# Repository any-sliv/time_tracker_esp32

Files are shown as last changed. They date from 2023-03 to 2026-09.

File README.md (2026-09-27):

# Cube Time Tracker ESP32

**:exclamation: --This project is still under heavy development. First release is coming!--**
**Desktop app - cube's receiving end is in development.**
</br>

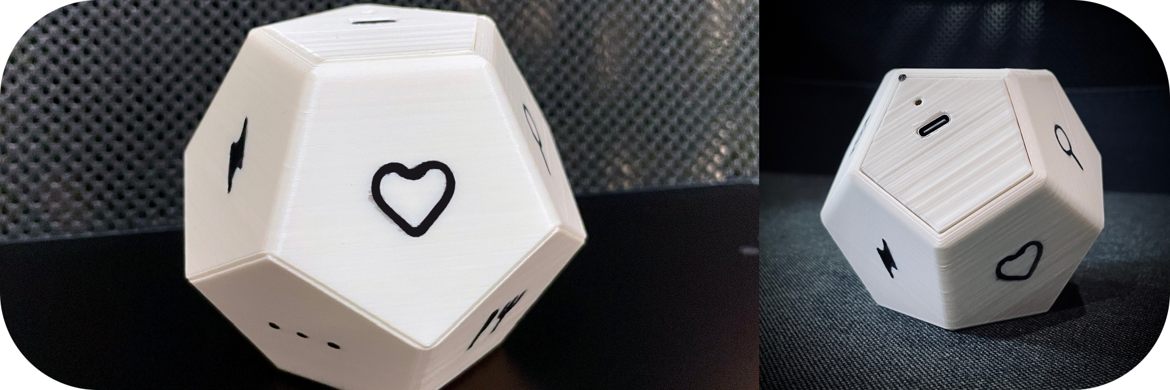
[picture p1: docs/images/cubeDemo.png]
:game_die: tracker
 

</br>

Open source time tracker in a form of cube :game_die: Each wall has a symbol which describes activity you might be doing. Flip the wall and the clock is ticking! Cube pairs with a **desktop app** (under development), which shows you the insights into time you spent on particular activities. 
</br>

In order to start with your own DIY tracker you will go through these steps:
- :hammer: Obtain and build (esp32 board, accelometer board, battery and enclosure)
- :arrow_double_up: Upload firmware to ESP32 board
- :mag: Connect to tracker with desktop app
- :rocket: Go thru initial configuration process

# Hardware Build

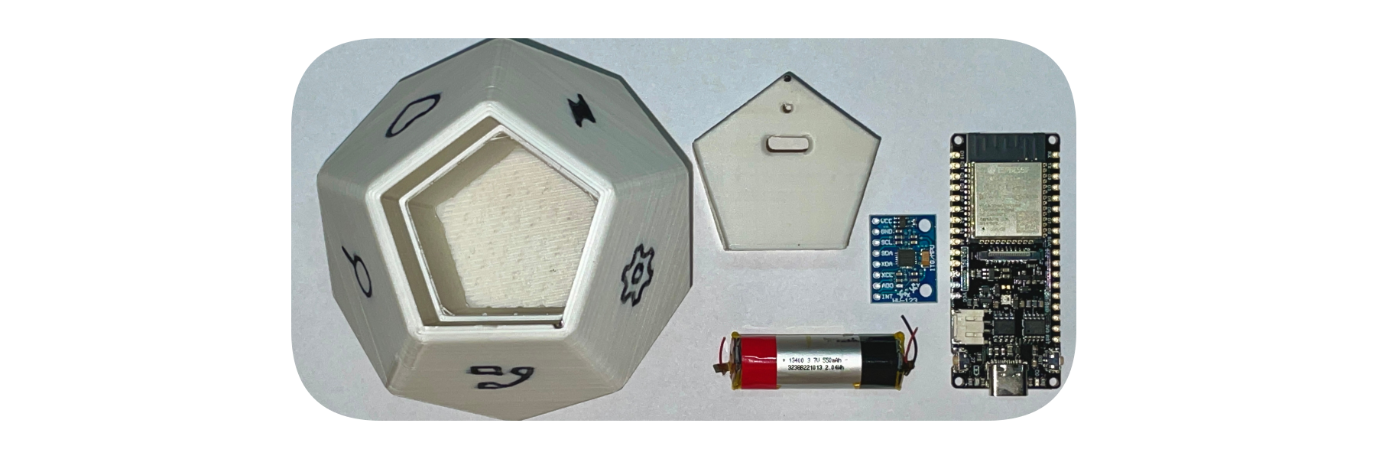
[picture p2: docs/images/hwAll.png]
All the elements


## Components

Alright, time to build the tracker :game_die: Here is the list of parts you need :gear:

- [DFRobot Firebeetle ESP32](https://wiki.dfrobot.com/FireBeetle_Board_ESP32_E_SKU_DFR0654) (currently the only supported board)
- [MPU6050 Accelometer](https://components101.com/sensors/mpu6050-module)
- Battery (lithium) of your choice, single cell, with the right shape you can fit any up to 1000mAh. Mind that Firebeetle has no any protection circuit
- 3D printed parts (models available in docs/ )
  - Enclosure 
  - Insert which will hold your electronics
- Two tiny screws

Equipment you might need for assembly:
- Soldering iron
- Tape (duct or double sided)
- Screwdriver

## Assembly

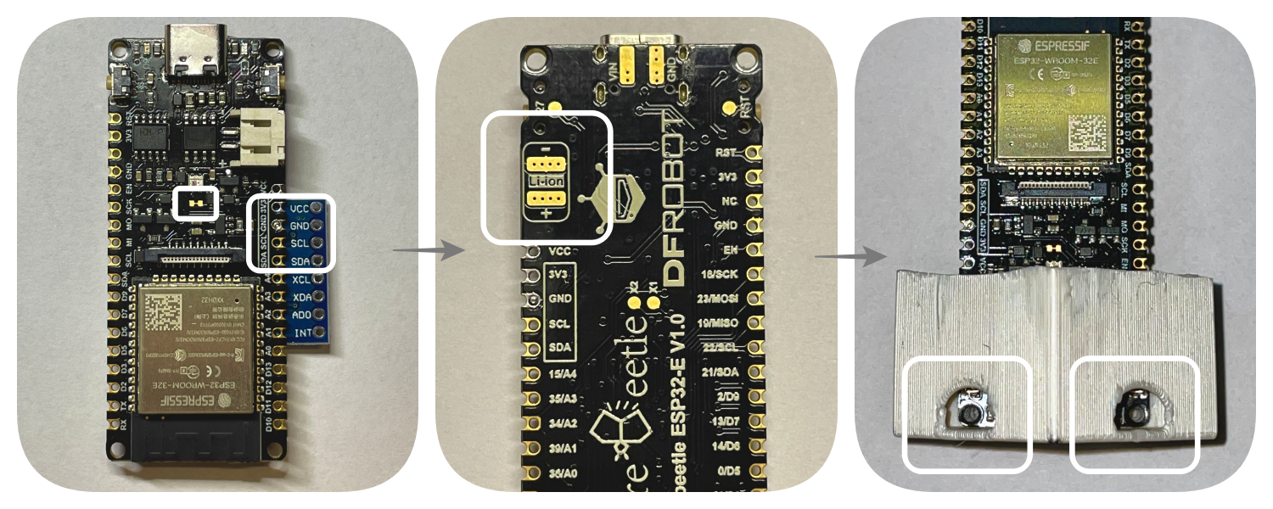
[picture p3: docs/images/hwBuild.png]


- Cut the trace between exposed pads (be careful not to cut the other traces)
- Solder MPU6050 to Firebeetle. Match the pins from MPU :exclamation: Mind that MPU's VCC pin should connect to 3V3 on the beetle
- Take your battery and solder its terminals to pads on the beetle's bottom side
- Attach battery to Firebeetle board (suggestion: tape)
- Put your assembled electronics into the printed insert and thighten screws through the holes in insert

:checkered_flag: I hope you didn't screw it up (lol you get it, the last step with screws).
</br>
Connect USB-C cable, charge the battery and upload software!

## Hardware additional info

### Power consumption

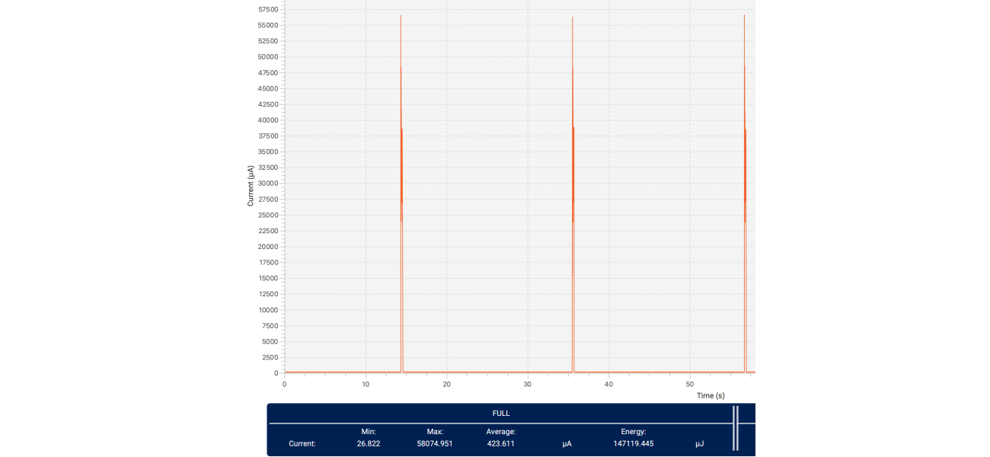
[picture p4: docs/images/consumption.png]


An average current consumption on FireBeetle is around 500uA. Time on battery you can calculate as follows: </br>`90% * capacity[mAh] / avg_consumption[mA] = time[h]`. </br> Other boards might yield different results. When looking for an alternative board pay attention to what components on the board are powered from 3V3 rail, an example is USB to UART converter present on almost every board, they are usually connected to 3V3, so they will drain your battery. Lolin32 Lite seems to be the closest suitable alternative, but since it has no connection from battery to ESP32 you might to hack a resistor divier and connect it to some analog input.
</br>
Cube app will remind you about low battery level.

# Software Build

Time to upload software into the tracker. Or you might want to tweak the software a lil bit on your own?

### Build 
Project is build with [PlatformIO](https://platformio.org) framework.

- Install PlatformIO extension in VSCode
- PIO Home > Platforms > Embedded > Download and install "Espressif 32" **version 6.1.0** (includes ESP-IDF v5.0.1)
- Make sure you cloned/pulled this git repository
- Download submodules `git submodule update --init` </br> NimBLE repo in {project}/app/ble/esp32-nimble-cpp should be downloaded. If not, use `git submodule add https://github.com/h2zero/esp-nimble-cpp` and then update submodule
- Build project and upload binaries using PlatformIO buttons/shortcuts at the bottom status bar

Off you go! In case of errors - clean and build.

## Troubleshooting
- Firebeetle board not recognized (OS X): http://www.wch-ic.com/downloads/CH341SER_MAC_ZIP.html

Otherwise... Plug the cube and run PlatformIO serial monitor, lookup the errors in the console

## Found a bug?
If you found a :bug: please report it via issues tab

## Known issues
Time drifts +/- 5%. 8.5 MHz internal RTC clock issue - to be fixed in upcoming ESP-IDF updates, you can implement it already using [esp-idf issue commit](https://github.com/espressif/esp-idf/commit/a0ed82525ec03bfe3a3edc46fbbb2c8449db3e14)

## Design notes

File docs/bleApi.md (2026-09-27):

# Time tracker ESP32 BLE API

This documentation provides information on the Bluetooth Low Energy (BLE) communication protocol API used in a time tracker. The documentation is organized into sections that correspond to the different services supported by the application. Each service includes one or more characteristics that describe the data being transmitted over BLE. The documentation also includes guidelines for developers and users.
</br>

### Tracker goes zzz...
The device is sleeping most of the time, what also means its BLE controller is turned off. Waking up happens once per five minutes or position has changed, and it advertises for a few seconds — so be quick and listen for it... basically always.
</br>
Once you are **connected**, the tracker holds itself awake for up to **30 seconds** rather than hanging up mid-transfer. It ends the session early when either the position backlog has been drained (see Position below) or you write the Sleep characteristic. Note that after it sleeps it may not advertise again for up to five minutes, so finish everything you need in one session.
</br>
Mind that tracker is a low power device and its juice comes from battery, so try use/read/write as least and quick as possible.
</br>

## Services and characteristics:
- **Service**
  - **Characteristic**
  - ...

### **Time tracker advertise** UUID: 8227dcb2-30e3-11ed-a261-0242ac120002
</br>

- **Device manufacturer name** (UUID:--)
  - **Device manufacturer name** (UUID:2A29)
    </br>
    .
    
- **Firmware revision** (UUID:--)
  - **Firmware revision** (UUID:2A26)
    </br>
     .
- **Battery** (UUID: --)
  - **Battery**
    </br>
    This is BT SIG adopted service. Data is a battery level [%]. Details: https://www.bluetooth.com/specifications/specs/battery-service/
    </br>
    Device updates value onRead action. Read twice to get actual value.

- **Current Time** (UUID: --)
  - **Current Time** (UUID: 2A2B)
    </br>
    | Data | Length (bytes) | Description | Properties |
    | -------- | -------- | -------- | -------- | 
    | int64_t | 8 | Epoch (unix) time | READ + WRITE |

    Device has no RTC battery, thus it might lose time. Using this characteristic device can have its system time updated.
    Device updates value onRead action. Read twice to get actual value.

- **Sleep** (UUID: --)
  - **Sleep** (UUID: 646b8837-cea9-4006-be25-00c990029e90)
    | Data | Length (bytes) | Description | Properties |
    | -------- | -------- | -------- | -------- | 
    | uint8_t | 1 | Sleep request | WRITE |

    Device stays in sleep mode most of the time. Use this characteristic to force device to enter sleep mode. Recommended to use after done with processing all data from the tracker. Write (uint8_t)<1> to force sleep.

- **IMU** (UUID: 7bef916a-3141-11ed-a261-0242ac120000)
  - **Position** (UUID: 7bef916a-3141-11ed-a261-0242ac120001)
    | Data | Length (bytes) | Description | Properties |
    | -------- | -------- | -------- | -------- | 
    | \<startTime>,\<face>[;\<startTime>,\<face>]... | variable, up to MTU-3 | Batch of tracker positions and their start times | READ |

    ASCII text. One read returns **as many records as fit in the negotiated MTU minus 3 bytes**, separated by `;`. Records are **oldest first**, and ordering holds across successive reads, so a client can simply append each batch.

    Example data (three records in one read):
    ```
    1688587818,8;1688589019,4;1688590151,8
    ```

    - `startTime` is decimal epoch (unix) seconds at which the face was registered.
    - `face` is the cube face. It may read **4294967295** (`-1` as unsigned), which means the tracker saw a position that matches none of its calibrated faces — treat it as "unknown", not as a real face.
    - **A single record is a valid batch of one**, so a client written against the older one-record-per-read format keeps working unchanged.
    - At a very small (unnegotiated, 23-byte) MTU a single record can exceed the budget. The tracker sends it anyway rather than stalling; the value is retrievable via a read-blob continuation.

    Each tracker flip is saved in order to be sent later, so a backlog accumulates while there is no BLE connection.
    </br> Device updates value onRead action. Read twice to get actual value. First read might be zero, always read at least twice.
    BLE Client should read as long as value in characteristic is other than 0, due to fact there might be more data to read than just from one position change.
    </br> Once the tracker has handed over at least one record and a subsequent read returns 0, it treats the backlog as drained and goes to sleep shortly after — so issue any other work (calibration, time set) before finishing the drain, or keep the connection busy.

  - **Calibration** (UUID: 7bef916a-3141-11ed-a261-0242ac120002)
    </br>
    | Data | Length (bytes) | Description | Properties |
    | -------- | -------- | -------- | -------- | 
    | \<status>,\<face> | 4-5 | Client request or server response | WRITE + READ |

    Calibration characteristic is used during initial configuration to calibrate IMU/accelometer. Requests from client initiate calibration and server responds with result and calibrated face number. Client initiates calibration of each position/face/wall with writing (uint8_t)<1> to the characteristic. Table below represents values server might set as a result.

    | Value | Definition |
    | -------- | -------- | 
    | -1 | Error, calibration failed |
    | 0 | Idle, calibration not initiated |
    | 1 | Position already exists/duplicate | 
    | 2 | Position registered OK | 
    | 3 | Calibration done |

    Flow of calibration process:
    - Client requests calibration - write (uint8_t)<1> to characteristic
    - Tracker responds with a write to characteristic with response from table above
    - Client reads from characteristic. If position OK/already exists - flip the cube/tracker
    - Client requests calibration - write (uint8_t)<1> to characteristic
    - ...
    - Until done

uuidDeviceFirmwareUpdateService = "00009921-1212-efde-1523-785feabcd123"; 
uuidDeviceFirmwareDataCharacteristic = "00009921-1212-efde-1523-785feabcd124"; 
uuidDeviceFirmwareControlCharacteristic = "00009921-1212-efde-1523-785feabcd125"; 

- **Device firmware update** (UUID:00009921-1212-efde-1523-785feabcd123)
  - **Device firmware control** (UUID:00009921-1212-efde-1523-785feabcd125)
    </br>
    DFU characteristic, use it for initiating update and checking status.

    | Value | Definition | Description |
    | -------- | -------- | -------- |
    | 0 | OTA Start Request | Send to server to request DFU begin |
    | 1 | OTA Start Request acknowledged | Server sets value |
    | 2 | OTA Start Request not acknowledged | Server sets value |
    | 3 | OTA Done Request | Send to server to request DFU end |
    | 4 | OTA Done Request acknowledged | Server sets value | 
    | 5 | OTA Done Request not acknowledged | Server sets value |

    Process flow:
    </br>
    Client requests DFU and after second reads from characteristic what server has responded. In case of success split firmware file (.bin) into chunks of a `chunkSize = BLE MTU size - 3`. Send all the chunks to data characteristic (no response). After sending all data, write a done request to this characteristic, wait 3-5 seconds and read a value if end has been acknowledged. If so, device will reboot in a couple of seconds.

  - **Device firmware update data** (UUID:00009921-1212-efde-1523-785feabcd124)
    </br>
    Send here chunks of firmware file

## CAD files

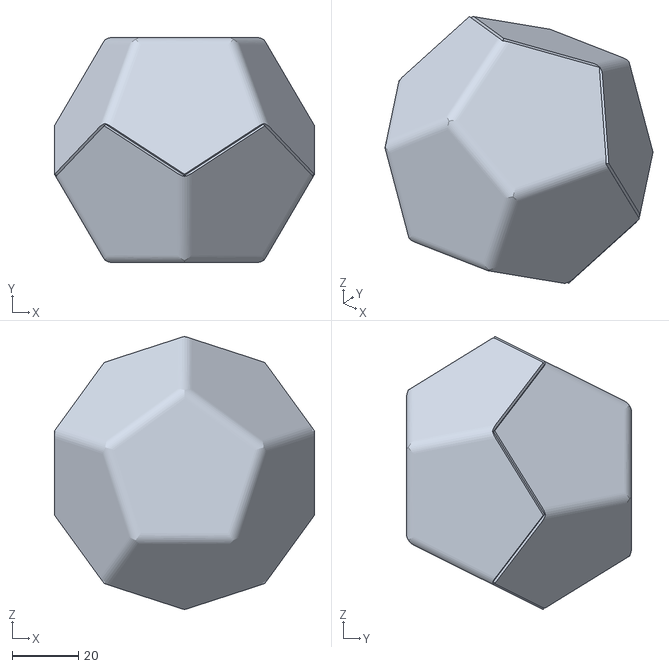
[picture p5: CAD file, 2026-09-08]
docs/3dmodel/cube.stl
78.5 x 68.0 x 82.5

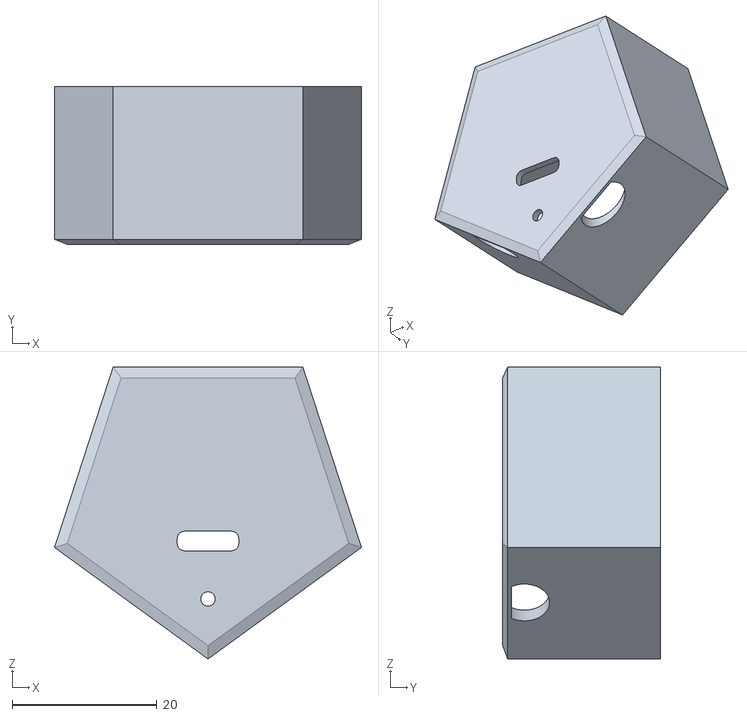
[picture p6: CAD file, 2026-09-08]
docs/3dmodel/cubeInsert.stl
42.4 x 21.8 x 40.3

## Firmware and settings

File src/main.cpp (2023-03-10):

/**
 * @file main.cpp
 * @author Maciej Sliwinski
 * @brief This file is a part of time_tracker_esp32 project.
 *
 * The code is distributed under the MIT License.
 * See the LICENCE file for more details.
 */

#include "appManagement.hpp"
#include "nvs.hpp"

extern "C" {
    #include <freertos/FreeRTOS.h>
    #include <freertos/task.h>
    #include <esp_system.h>
    #include <sdkconfig.h>
    #include "esp_ota_ops.h"
} // extern C close

extern "C" void app_main() {
    const esp_partition_t *running_partition = esp_ota_get_running_partition();
    ESP_LOGI(__FILE__, "%s:%d. Boot on partition: %s", __func__ ,__LINE__, running_partition->label);

    BaseType_t res = pdFAIL;

    res = xTaskCreatePinnedToCore(APP::AppManagementTask, "AppManagementTask", TASK_STACK_DEPTH_NORMAL, NULL, 
                                        TASK_PRIORITY_NORMAL, NULL, 0);
    configASSERT(res);
    // ESP_ERROR_CHECK(esp_event_loop_create_default());

    NVS::Nvs nvs;
    ESP_ERROR_CHECK(nvs.init());

    while (1) {
        vTaskDelay(10 / portTICK_PERIOD_MS);  // keep it, otherwise watchdog is not fed
    }
}


/* --------------------------------------- END OF FILE ------------------------------------------- */

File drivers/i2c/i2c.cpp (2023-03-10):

/**
 * @file main.cpp
 * @author Maciej Sliwinski
 * @brief This file is a part of time_tracker_esp32 project.
 *
 * The code is distributed under the MIT License.
 * See the LICENCE file for more details.
 */

#include "i2c.hpp"

#define I2C_MASTER_FREQ_HZ 400000

I2C::I2C(gpio_num_t scl, gpio_num_t sda, i2c_port_t port) {
     this -> port = port;
    conf.mode = I2C_MODE_MASTER;
    conf.sda_io_num = sda;
    conf.sda_pullup_en = GPIO_PULLUP_ENABLE;
    conf.scl_io_num = scl;
    conf.scl_pullup_en = GPIO_PULLUP_ENABLE;
    conf.master.clk_speed = I2C_MASTER_FREQ_HZ;
    conf.clk_flags = 0;
    i2c_param_config(port, &conf);
    i2c_driver_install(port, conf.mode, 0, 0, 0);
}

I2C::~I2C() {
    i2c_driver_delete(port);
}

bool I2C::slave_write(uint8_t slave_addr,uint8_t reg_addr, uint8_t data) {
    i2c_cmd_handle_t cmd = i2c_cmd_link_create();
    i2c_master_start(cmd);
    i2c_master_write_byte(cmd, slave_addr << 1, 1);
    i2c_master_write_byte(cmd, reg_addr, 1);
    i2c_master_write_byte(cmd, data, 1);
    i2c_master_stop(cmd);
    int ret = i2c_master_cmd_begin(port, cmd, 1000 / portTICK_PERIOD_MS);
    i2c_cmd_link_delete(cmd);
    if (ret == ESP_FAIL) {
        return false;
    }
    return true;
}

bool I2C::slave_read(uint8_t slave_addr, uint8_t data, uint8_t *buf, uint32_t len) {
    i2c_cmd_handle_t cmd = i2c_cmd_link_create();
    i2c_master_start(cmd);
    i2c_master_write_byte(cmd, slave_addr << 1, 1);
    i2c_master_write_byte(cmd, data, 1);
    i2c_master_stop(cmd);
    int ret = i2c_master_cmd_begin(port, cmd, 1000 / portTICK_PERIOD_MS);
    i2c_cmd_link_delete(cmd);
    if (ret == ESP_FAIL) {
        return false;
    }

    cmd = i2c_cmd_link_create();
    i2c_master_start(cmd);
    i2c_master_write_byte(cmd, slave_addr << 1 | 1, 1);
    while(len) {
        i2c_master_read_byte(cmd, buf,(i2c_ack_type_t)(len == 1));
        buf++;
        len--;
    }
    i2c_master_stop(cmd);
    ret = i2c_master_cmd_begin(port, cmd, 1000 / portTICK_PERIOD_MS);
    i2c_cmd_link_delete(cmd);
    if (ret == ESP_FAIL) {
        return false;
    }

    return true;
}

uint8_t I2C::slave_read_byte(uint8_t slave_addr, uint8_t reg) {
    i2c_cmd_handle_t cmd = i2c_cmd_link_create();
    i2c_master_start(cmd);
    i2c_master_write_byte(cmd, slave_addr << 1, 1);
    i2c_master_write_byte(cmd, reg, 1);
    i2c_master_stop(cmd);
    i2c_master_cmd_begin(port, cmd, 1000 / portTICK_PERIOD_MS);
    i2c_cmd_link_delete(cmd);

    uint8_t buf;
    cmd = i2c_cmd_link_create();
    i2c_master_start(cmd);
    i2c_master_write_byte(cmd, slave_addr << 1 | 1, 1);
    i2c_master_read_byte(cmd, &buf, (i2c_ack_type_t)1);
    i2c_master_stop(cmd);
    i2c_master_cmd_begin(port, cmd, 1000 / portTICK_PERIOD_MS);
    i2c_cmd_link_delete(cmd);
    return buf;
}

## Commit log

2023-03-14 Low power trace cut
2023-03-14 Decreased wake up time, increased IMU task freq
2026-09-08 3d models
    [cube.stl, cubeInsert.stl]
2026-09-27 3d model
    [cube.stl, cubeInsert.stl]
